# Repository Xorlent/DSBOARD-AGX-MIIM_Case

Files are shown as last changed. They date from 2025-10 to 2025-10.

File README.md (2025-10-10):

# DSBOARD-AGX-MIIM_Case
3D-printable desktop case for a ForeCR DSBOARD-AGX-MIIM v.1.1
### Instructions
1. Print all using .25mm layer height, .2mm first layer, 3 wall loops, 15% infill
   - No supports
   - Add a 3mm brim to the left print object if your printer is prone to knocking into models
2. Test fit the printed parts to ensure successful assembly
3. Using the appropriate assembly glue based on the filament:
   - Glue the right and left prints together, then immediately glue the right and left assembly to the base
   - Allow to cure
4. Unscrew the 80mm fan from the Jetson module, making note of its orientation.
5. Insert the fan in the cavity beneath the base
6. Pull the fan wiring through the holes within the base and connect to the fan header on the DSBOARD-AGX-MIIM
7. Place the Jetson module and DSBOARD assembly on top of the base
8. Using the original screws, reassemble the fan to the Jetson module.  Do not overtighen. 
9. Do not glue the lid; it is press-fit to allow for easy access to the PCB  
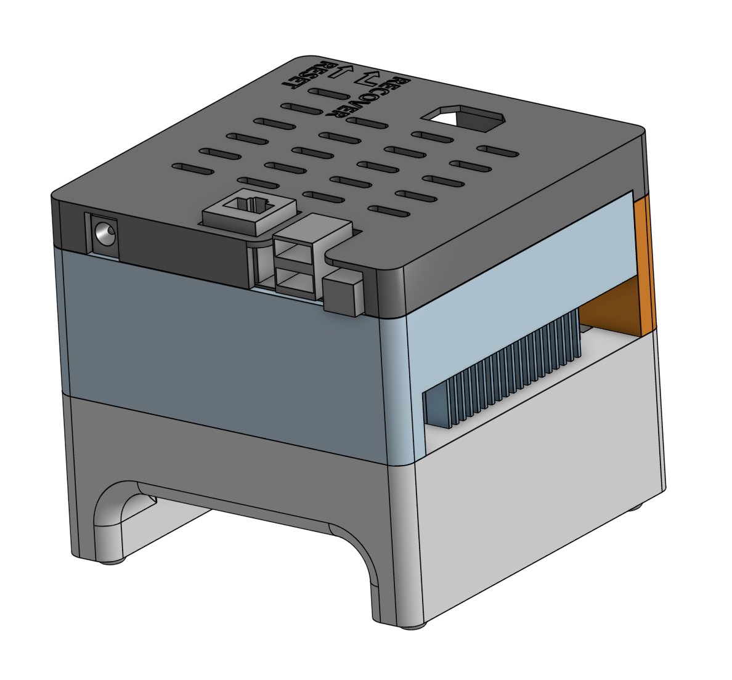
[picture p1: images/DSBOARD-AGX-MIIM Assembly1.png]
Assembled Case Image 1

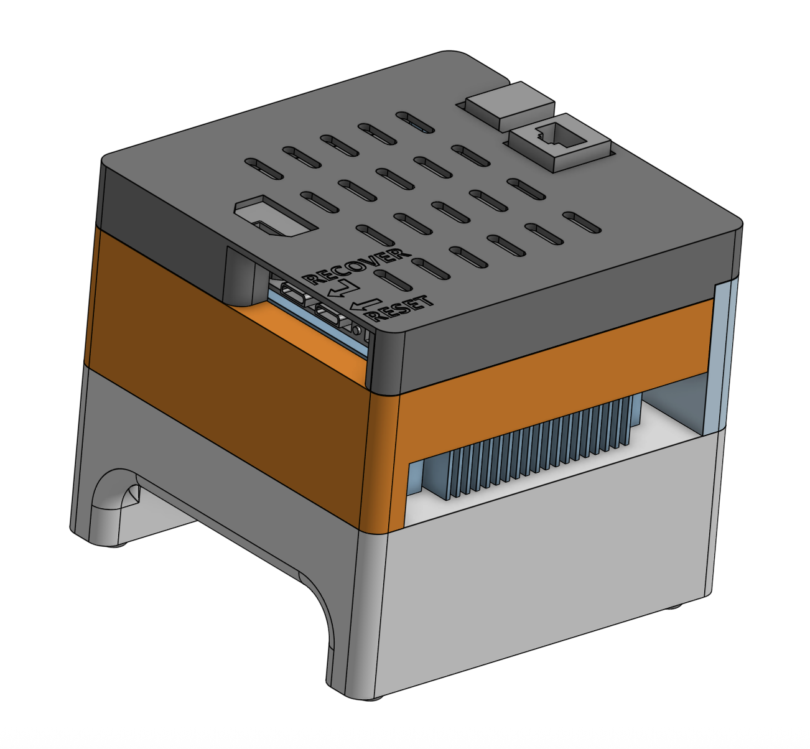
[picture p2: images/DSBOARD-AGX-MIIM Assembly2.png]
Assembled Case Image 2


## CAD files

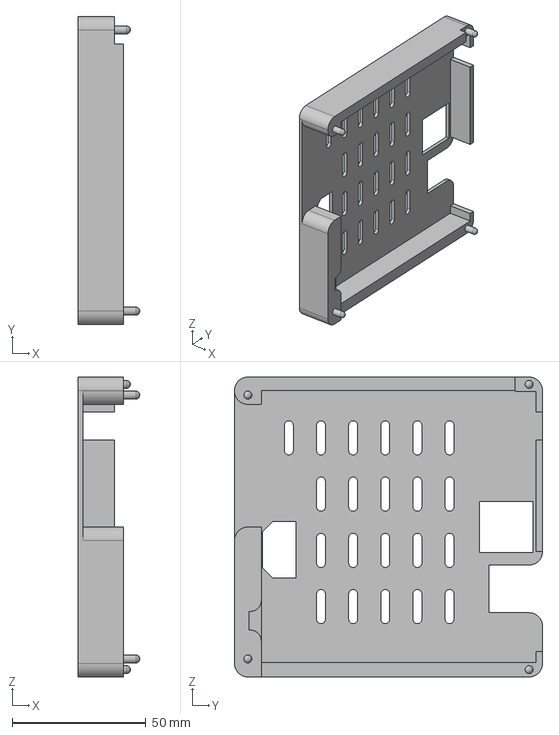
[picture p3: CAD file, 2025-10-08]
DSBOARD-AGX-MIIM Lid.step
23.0 x 115.0 x 112.0 mm

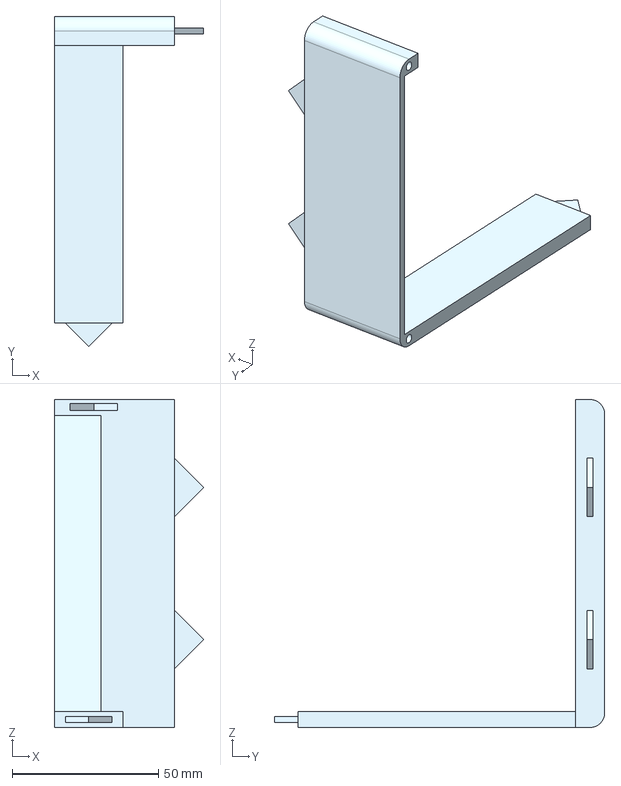
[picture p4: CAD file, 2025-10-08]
DSBOARD-AGX-MIIM Right.step
51.0 x 112.8 x 112.0 mm

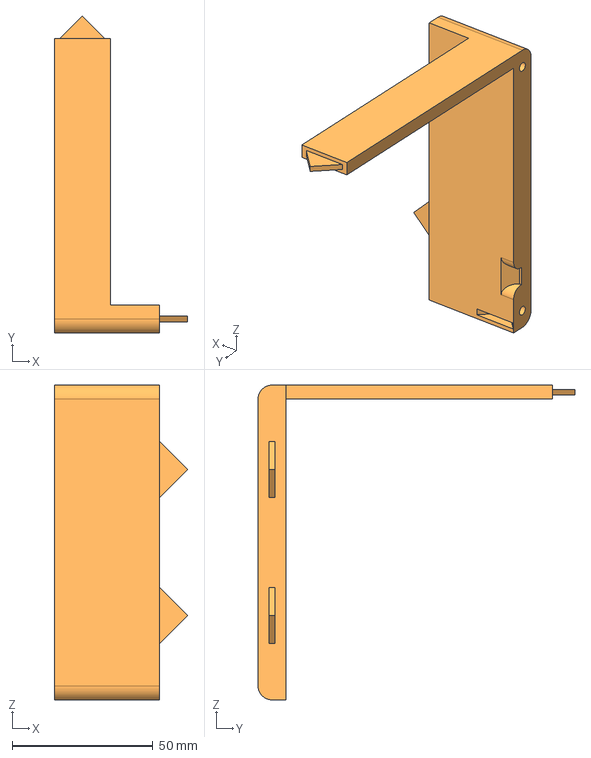
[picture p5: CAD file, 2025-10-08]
DSBOARD-AGX-MIIM Left.step
47.5 x 112.8 x 112.0 mm

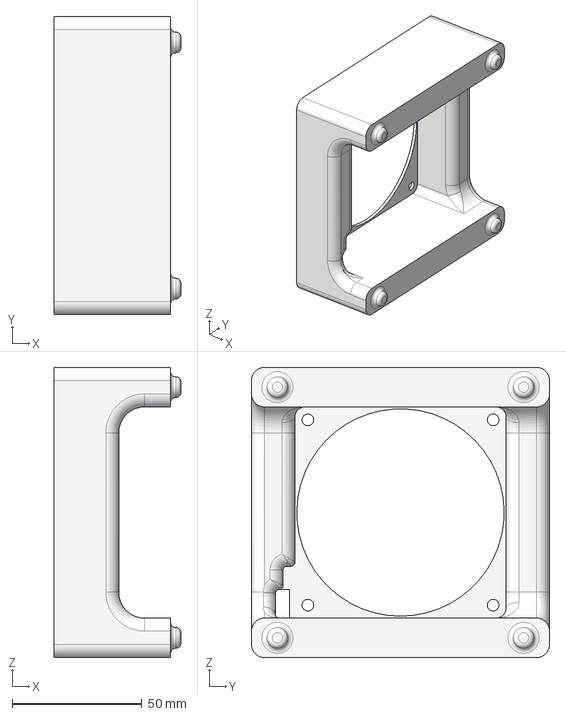
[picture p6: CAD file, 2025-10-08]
DSBOARD-AGX-MIIM Base.step
49.0 x 115.0 x 112.0 mm
